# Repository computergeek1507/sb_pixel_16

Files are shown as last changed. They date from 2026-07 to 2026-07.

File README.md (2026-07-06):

# SBPixel16




A 16-port WS2812 pixel controller built on the **ESP32-P4**. It drives all 16 LED
strips simultaneously using the ESP32-P4's PARLIO peripheral for glitch-free parallel
DMA output. Pixel data comes from Ethernet (E1.31/sACN or DDP) or from **FSEQ
sequences played off a microSD card** in a standalone loop.

> **⚠️ WIP — Do not use.** Both the hardware and firmware are under active
> development and have not been fully validated.

This repository contains both the open-source **hardware** (KiCad 10) and the
**firmware** (Arduino / ESP-IDF).

---

## Features

- **16 parallel pixel outputs** — all strips clocked out together via PARLIO DMA,
  no RMT channel juggling.
- **Network input** — E1.31 (sACN, UDP 5568) or DDP (UDP 4048), selectable at runtime.
- **Standalone FSEQ playback** — plays uncompressed FSEQ v2 sequences (full or sparse)
  from a microSD card, looping the whole `/sequences` folder forever. No network needed.
- **Single-universe DMX512 output** — optional, generated on UART1 (250 kbaud, 8N2).
- **Web UI + REST API** — configure network, protocol, and per-port settings from a
  browser; config persists in LittleFS as `/config.json`.
- **On-OLED network setup** — set DHCP / static IP / gateway from the front-panel
  buttons, no computer required.
- **Over-the-air updates** — firmware and filesystem images can be flashed from the web UI.
- **Per-port configuration** — pixel count, start channel, color order, brightness,
  null/sacrificial pixels, and pixel grouping.
- **On-board 128×64 SSD1306 OLED** — shows IP, protocol, FPS, packet count, input
  voltages, SD status, and the currently playing sequence.
- **Two input-voltage monitors** — oversampled ADC readings (V1/V2) shown on the OLED.
- **Built-in test patterns** — cycle red / green / blue / rainbow with the on-board
  buttons; power-up RGB self-test on every boot.

---

## Repository layout

```
.
├── firmware/SBPixel16/     Arduino sketch (ESP32-P4)
│   ├── SBPixel16.ino        main app: setup/loop, config, Ethernet, parsers
│   ├── SBPixel16.h          board pin map & config structs
│   ├── parlio_ws2812.h      PARLIO parallel WS2812 DMA driver
│   ├── dmx_output.h         single-universe DMX512 output
│   ├── fseq_player.h        microSD FSEQ v2 player (uncompressed/sparse)
│   ├── net_menu.h           two-button OLED network editor
│   ├── data/                web UI source (packed into the LittleFS image)
│   └── page_*.h             web UI pages + REST API handlers
├── hardware/                KiCad 10 project (schematics, PCB, libraries)
│   └── ESP32-P4_16.*        board design files
└── LICENSE                  CC BY-NC 4.0 (firmware)
```

---

## Firmware

### Target

- **Board:** ESP32-P4 (Arduino-ESP32 3.x), e.g. Waveshare ESP32-P4-ETH
- **Ethernet PHY:** IP101GRI (RMII)
- **microSD:** the module's SDIO slot (4-bit) — used for FSEQ playback
- **Partition:** Default 4MB with SPIFFS (1.2 MB app / 1.5 MB filesystem)

### Required libraries

Install via the Arduino Library Manager:

| Library | Source |
| --- | --- |
| ESPAsyncWebServer | github.com/ESP32Async/ESPAsyncWebServer |
| AsyncTCP | github.com/ESP32Async/AsyncTCP |
| ArduinoJson | arduinojson.org |
| Adafruit GFX + Adafruit SSD1306 | Adafruit (OLED display) |

### Build & flash

1. Install the ESP32 board package (Arduino-ESP32 **3.x**) and select an **ESP32-P4** board.
2. **Enable PSRAM** (Tools → PSRAM → *Enabled* = `-DBOARD_HAS_PSRAM`). The module has
   PSRAM but the board default is *Disabled*, which leaves it uninitialized.
3. Set the partition scheme to **Default 4MB with SPIFFS**.
4. Open `firmware/SBPixel16/SBPixel16.ino`, compile, and upload.
5. Upload the web UI: flash the LittleFS filesystem image — a prebuilt
   `SBPixel16.littlefs.bin` is provided, or re-flash it over the air from the web UI.

On first boot with no `/config.json`, the firmware writes sensible defaults
(DHCP on, E1.31, 100 pixels/port, RGB order, 30% brightness).

**Board revisions:** the default build targets **HW1** (original pin map). Build for
the revised **HW2** board (pixel ports 12–16 rerouted off the USB pins onto
GPIO32/33/46/47/48) with `-DHW_VERSION=2`.

**Prebuilt binaries:** every push builds HW1 + HW2 firmware and the KiCad fabrication
outputs in CI — download them from the repo's **Actions** tab. When flashing over
serial after an OTA, use the `.merged.bin` (or first `esptool erase-region 0xe000
0x2000`), otherwise the bootloader keeps booting the previous OTA partition.

### REST API

| Method | Endpoint | Purpose |
| --- | --- | --- |
| GET | `/api/status` | Runtime stats (FPS, packet counts, voltages, SD/FSEQ status) |
| GET | `/api/config` | Current configuration as JSON |
| POST | `/api/config` | Update configuration |
| POST | `/api/reboot` | Reboot the controller |
| POST | `/api/ota/firmware` | Upload a firmware image |
| POST | `/api/ota/filesystem` | Upload a filesystem (web UI) image |

### Key defaults

- Refresh rate: ~40 fps (25 ms frame interval)
- Max pixels per port: 340 (configurable in `SBPixel16.h`)
- Input protocols: `0` = E1.31, `1` = DDP, `2` = FSEQ (SD card)
- Data timeout: outputs blank after 1 s with no packets
- E1.31 UDP port 5568 · DDP UDP port 4048 · HTTP port 80

### Front-panel controls (two buttons)

| Button | Action |
| --- | --- |
| **BTN1** tap | Cycle test pattern: Off → Red → Green → Blue → Rainbow → Off |
| **BTN2** tap | Stop the test pattern |
| **BTN2** hold (~1.5 s) | Open the `NETWORK SETUP` menu on the OLED |

**In the network menu:** **BTN1** changes the value under the cursor (hold to
auto-repeat), **BTN2** advances to the next field. Order: DHCP on/off → IP →
gateway → *Save & reboot*. Saving writes the config and reboots; 30 s of inactivity
cancels. Lets you set a static IP without a computer.

### FSEQ playback (microSD)

The microSD card is mounted at boot in every mode — its status shows on the OLED
(a card icon in the header) and the web dashboard. Set the input protocol to **FSEQ**
(Network page, or `protocol: 2`) to play from it: the controller scans **`/sequences`**
for `*.fseq` files, plays them alphabetically, and loops the whole folder forever — no
network connection required.

- **Format:** FSEQ v2, **uncompressed only** (full or sparse frames). Export from
  xLights / FPP with *No Compression*. Compressed files are skipped.
- **Channel mapping:** frame channels map to ports by each port's **Start Ch.**, exactly
  like E1.31/DDP — so brightness, color order, and grouping all still apply.
- The OLED and the web dashboard show the mounted card and the sequence now playing.

---

## Hardware

The board is a KiCad 10 open-hardware design (`hardware/ESP32-P4_16.*`) with 16 buffered
pixel outputs, dual power inputs with voltage monitoring, an SSD1306 OLED, two buttons,
and RMII Ethernet.

Design files, interactive BOM, and part list are published on the upstream project:

- **Interactive BOM:** https://computergeek1507.github.io/PB_16/ESP32-P4_16/bom/ibom
- **Part BOM (.ods):** https://github.com/computergeek1507/PB_16/raw/master/ESP32-P4_16/ESP32-P4_16_BOM.ods

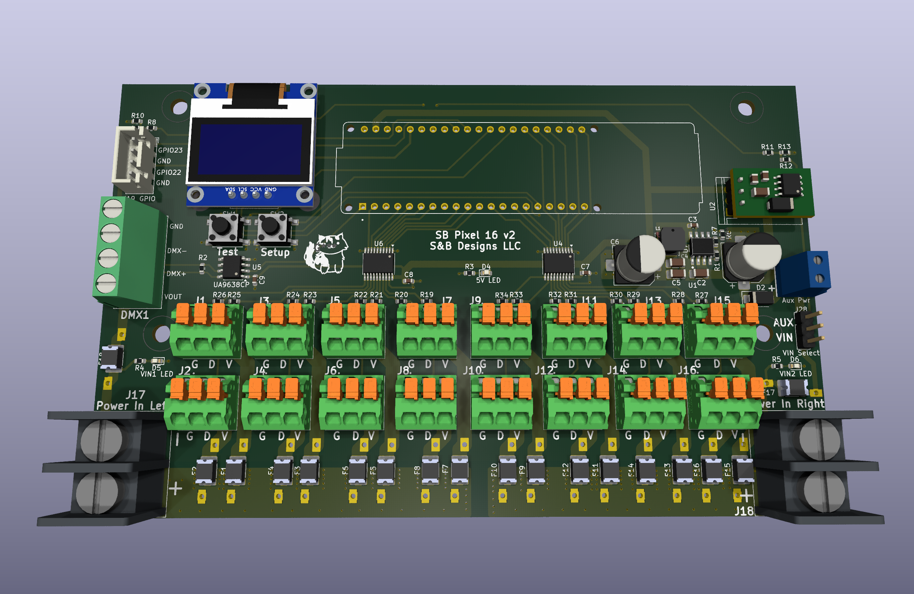
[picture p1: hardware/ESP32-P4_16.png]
ESP32-P4 16 board


---

## Licensing

Both the **firmware** and the **hardware** are licensed under **CC BY-NC 4.0**
(see [LICENSE](LICENSE)) — free to share and adapt for non-commercial use with
attribution.

Copyright © 2025 Scott Hanson.

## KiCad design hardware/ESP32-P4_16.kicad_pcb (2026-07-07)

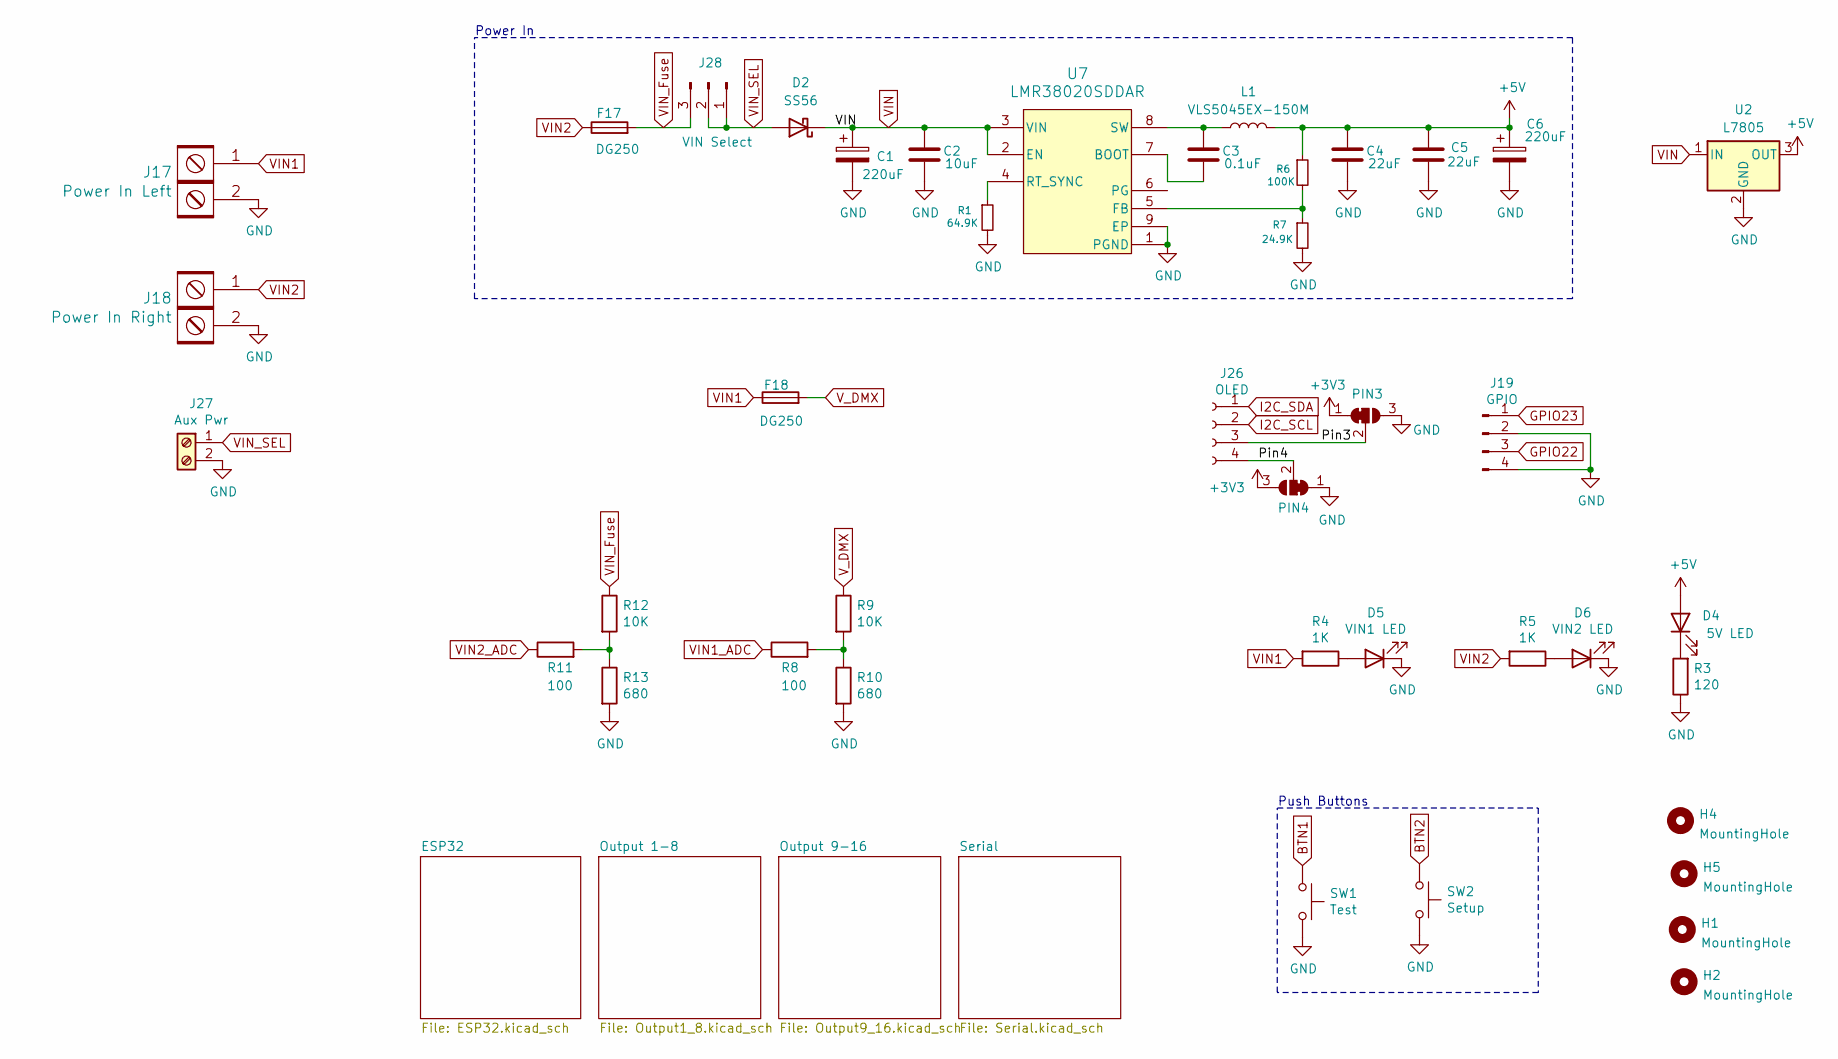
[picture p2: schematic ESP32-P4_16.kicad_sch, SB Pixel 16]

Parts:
C1, C6: 220uF; CP_Elec_8x10.5; LCSC C3340
C2: 10uF; C_1206_3216Metric; LCSC_PN C13585
C3: 0.1uF; C_0603_1608Metric; MPN CC0603KRX7R9BB104; LCSC C14663
C4, C5: 22uF; C_1206_3216Metric; LCSC_PN C1859
D2: SS56; D_SMA; LCSC C65009
D4: 5V LED; LED_0603_1608Metric; MPN LTST-C190KRKT; Digi-Key_PN 160-1436-2-ND
D5: VIN1 LED; LED_0603_1608Metric; MPN LTST-C190KRKT; Digi-Key_PN 160-1436-2-ND
D6: VIN2 LED; LED_0603_1608Metric; MPN LTST-C190KRKT; Digi-Key_PN 160-1436-2-ND
F17: DG250; Fuse_1812_4532Metric; MPN 3544-2
F18: DG250; Fuse_1812_4532Metric
H1, H2, H4, H5: MountingHole; MountingHole_3.7mm
J17: Power In Left; BARRIER_BLOCK_1ROW_2POS_P9.5MM; MPN OSTYK51102030; Digi-Key_PN ED2953-ND
J18: Power In Right; BARRIER_BLOCK_1ROW_2POS_P9.5MM; MPN OSTYK51102030; Digi-Key_PN ED2953-ND
J19: GPIO; JST_XH_B4B-XH-A_1x04_P2.50mm_Vertical; MPN B4B-XH-A(LF)(SN); Digi-Key_PN 455-2249-ND
J26: OLED; OLED-SSD1306-128X64-I2C-THT_2HOLE; MPN PPTC041LFBN-RC; Digi-Key_PN S7002-ND
J27: Aux Pwr; PHOENIX_MKDS1_2-3.81; MPN 1727010; Digi-Key_PN 277-1947-ND
J28: VIN Select; PinHeader_1x03_P2.54mm_Vertical; MPN 61300311121; Digi-Key_PN 732-5316-ND
L1: VLS5045EX-150M; IND_VLS5045EX-150M; MPN VLS5045EX-150M; Digi-Key_PN 445-174845-1-ND
PIN3: Jumper; SolderJumper-3_P1.3mm_Bridged12_Pad1.0x1.5mm
PIN4: JUMPER; SolderJumper-3_P1.3mm_Bridged12_Pad1.0x1.5mm
R1: 64.9K; R_0603_1608Metric; LCSC C14891
R3: 120; R_0603_1608Metric; MPN CRGCQ0603F120R; Digi-Key_PN A129677CT-ND
R4, R5: 1K; R_0603_1608Metric; MPN RC0603FR-071KL; Digi-Key_PN 311-1.00KHRTR-ND
R6: 100K; R_0603_1608Metric; LCSC C25803
R7: 24.9K; R_0603_1608Metric; LCSC C25962
R8, R11: 100; R_0603_1608Metric; MPN RMCF0603FT100R; Digi-Key_PN RMCF0603FT100RCT-ND
R9, R12: 10K; R_0603_1608Metric; MPN RC0603FR-0710KL; Digi-Key_PN 311-10.0KHRCT-ND
R10, R13: 680; R_0603_1608Metric; MPN RC0603FR-07680RL; Digi-Key_PN 311-680HRCT-ND
SW1: Test; SW_Push_1P1T_NO_6x6mm_H9.5mm; MPN PTS645SL50SMTR92 LFS; Digi-Key_PN CKN9088CT-ND
SW2: Setup; SW_Push_1P1T_NO_6x6mm_H9.5mm; MPN PTS645SL50SMTR92 LFS; Digi-Key_PN CKN9088CT-ND
U2: L7805; OKI-78SR_Horz
U7: LMR38020SDDAR; DDA0008E-IPC_A; MPN LMR38020SDDAR; Digi-Key_PN 296-LMR38020SDDARCT-ND

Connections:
+3V3: PIN3.1 (A), PIN4.3 (B); also elsewhere on the board
+5V: C4.1, C5.1, C6.1, D4.2 (A), L1.2, R6.1, U2.3 (OUT); also elsewhere on the board
/Pin3: J26.3, PIN3.2 (C)
/Pin4: J26.4, PIN4.2 (C)
BTN1: SW1.1; also elsewhere on the board
BTN2: SW2.1; also elsewhere on the board
GND: C1.2, C2.2, C4.2, C5.2, C6.2, D5.1 (K), D6.1 (K), J17.2, J18.2, J19.2, J19.4, J27.2, PIN3.3 (B), PIN4.1 (A), R1.2, R3.1, R7.2, R10.2, R13.2, SW1.2, SW2.2, U2.2 (GND), U7.1 (PGND), U7.9 (EP); also elsewhere on the board
GPIO22: J19.3; also elsewhere on the board
GPIO23: J19.1; also elsewhere on the board
I2C_SCL: J26.2; also elsewhere on the board
I2C_SDA: J26.1; also elsewhere on the board
unnamed: D4.1 (K), R3.2
unnamed: D5.2 (A), R4.1
unnamed: D6.2 (A), R5.1
unnamed: R8.2, R9.2, R10.1
unnamed: R11.2, R12.2, R13.1
unnamed: C3.2, U7.7 (BOOT)
unnamed: R6.2, R7.1, U7.5 (FB)
unnamed: R1.1, U7.4 (RT_SYNC)
unnamed: C3.1, L1.1, U7.8 (SW)
VIN: C1.1, C2.1, D2.1 (K), U2.1 (IN), U7.2 (EN), U7.3 (VIN)
VIN1: F18.1, J17.1, R4.2; also elsewhere on the board
VIN1_ADC: R8.1; also elsewhere on the board
VIN2: F17.1, J18.1, R5.2; also elsewhere on the board
VIN2_ADC: R11.1; also elsewhere on the board
VIN_Fuse: F17.2, J28.3, R12.1
VIN_SEL: D2.2 (A), J27.1, J28.1, J28.2
V_DMX: F18.2, R9.1; also elsewhere on the board

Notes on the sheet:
Push Buttons
Power In

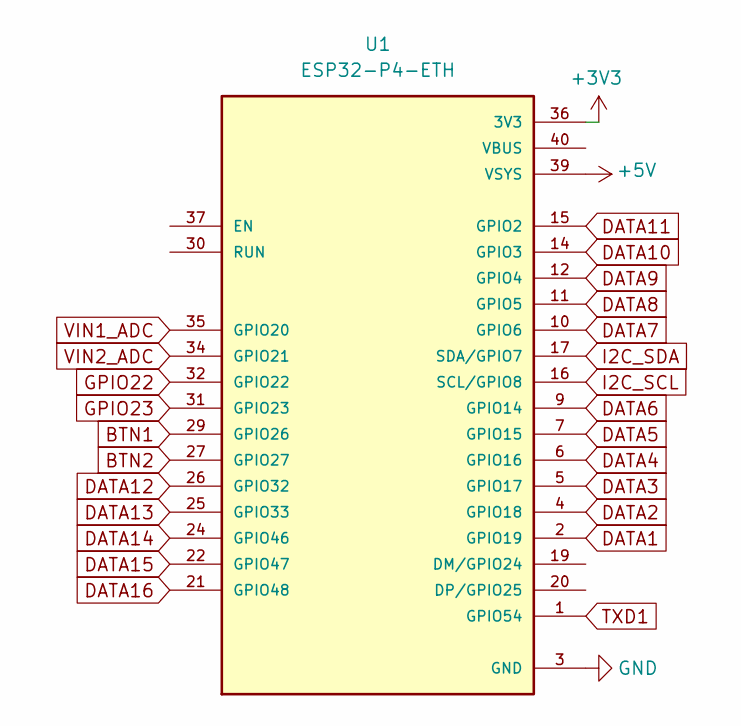
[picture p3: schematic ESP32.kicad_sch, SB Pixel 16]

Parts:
U1: ESP32-P4-ETH; MODULE_ESP32-P4-ETH

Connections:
+3V3: U1.36 (3V3); also elsewhere on the board
+5V: U1.39 (VSYS); also elsewhere on the board
BTN1: U1.29 (GPIO26); also elsewhere on the board
BTN2: U1.27 (GPIO27); also elsewhere on the board
DATA1: U1.2 (GPIO19); also elsewhere on the board
DATA2: U1.4 (GPIO18); also elsewhere on the board
DATA3: U1.5 (GPIO17); also elsewhere on the board
DATA4: U1.6 (GPIO16); also elsewhere on the board
DATA5: U1.7 (GPIO15); also elsewhere on the board
DATA6: U1.9 (GPIO14); also elsewhere on the board
DATA7: U1.10 (GPIO6); also elsewhere on the board
DATA8: U1.11 (GPIO5); also elsewhere on the board
DATA9: U1.12 (GPIO4); also elsewhere on the board
DATA10: U1.14 (GPIO3); also elsewhere on the board
DATA11: U1.15 (GPIO2); also elsewhere on the board
DATA12: U1.26 (GPIO32); also elsewhere on the board
DATA13: U1.25 (GPIO33); also elsewhere on the board
DATA14: U1.24 (GPIO46); also elsewhere on the board
DATA15: U1.22 (GPIO47); also elsewhere on the board
DATA16: U1.21 (GPIO48); also elsewhere on the board
GND: U1.3 (GND), U1.8 (GND), U1.13 (GND), U1.18 (GND), U1.23 (GND), U1.28 (GND), U1.33 (GND), U1.38 (GND); also elsewhere on the board
GPIO22: U1.32 (GPIO22); also elsewhere on the board
GPIO23: U1.31 (GPIO23); also elsewhere on the board
I2C_SCL: U1.16 (SCL/GPIO8); also elsewhere on the board
I2C_SDA: U1.17 (SDA/GPIO7); also elsewhere on the board
TXD1: U1.1 (GPIO54); also elsewhere on the board
VIN1_ADC: U1.35 (GPIO20); also elsewhere on the board
VIN2_ADC: U1.34 (GPIO21); also elsewhere on the board

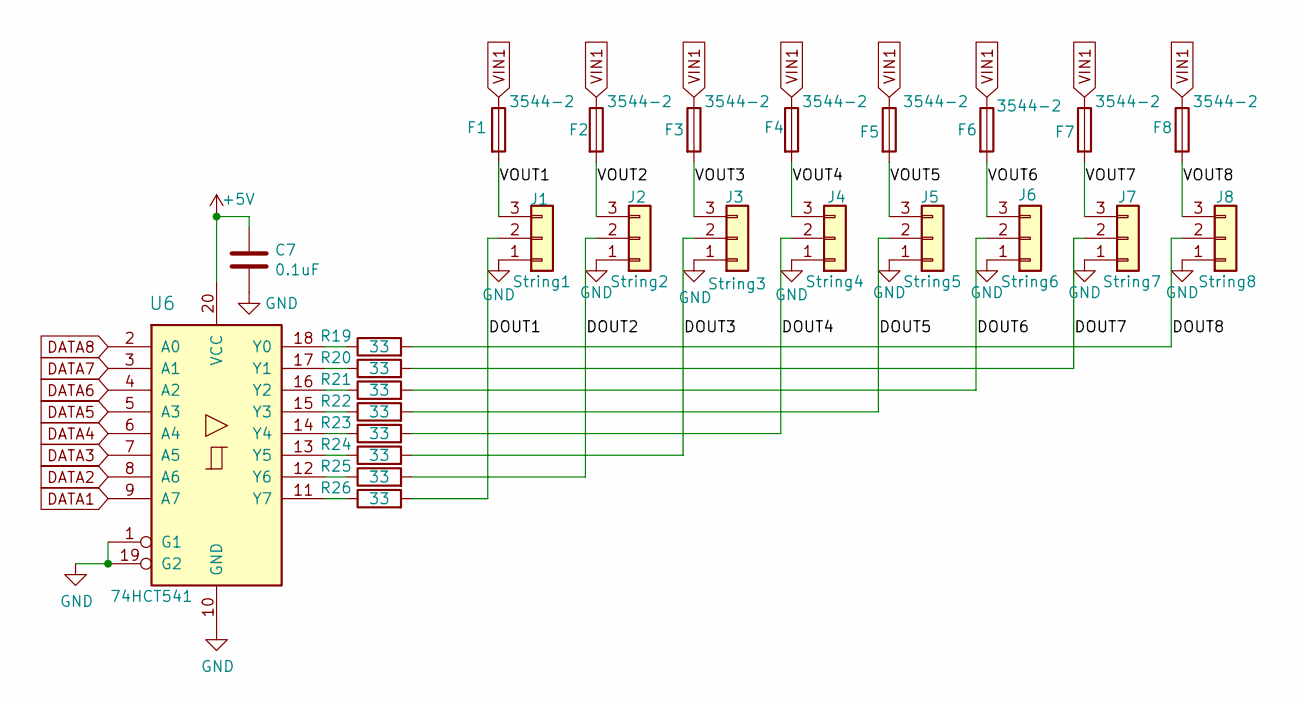
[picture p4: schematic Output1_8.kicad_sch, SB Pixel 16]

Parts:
C7: 0.1uF; C_0603_1608Metric; MPN CL10B104KB8NNWC; Digi-Key_PN 1276-1935-2-ND
F1, F2, F3, F4, F5, F6, F7, F8: 3544-2; Fuse_1812_4532Metric; MPN 3544-2
J1: String1; PHOENIX_1864299_1; MPN 1843619/OSTTJ0311530
J2: String2; PHOENIX_1864299_1; MPN 1843619/OSTTJ0311530
J3: String3; PHOENIX_1864299_1; MPN 1843619/OSTTJ0311530
J4: String4; PHOENIX_1864299_1; MPN 1843619/OSTTJ0311530
J5: String5; PHOENIX_1864299_1; MPN 1843619/OSTTJ0311530
J6: String6; PHOENIX_1864299_1; MPN 1843619/OSTTJ0311530
J7: String7; PHOENIX_1864299_1; MPN 1843619/OSTTJ0311530
J8: String8; PHOENIX_1864299_1; MPN 1843619/OSTTJ0311530
R19, R20, R21, R22, R23, R24, R25, R26: 33; R_0603_1608Metric; MPN CN34J330CT; LCSC C23140
U6: 74HCT541; TSSOP-20_4.4x6.5mm_P0.65mm; MPN SN74HCT541PWR; Digi-Key_PN MC74HCT541ADTR2GOSTR-ND

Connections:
+5V: C7.1, U6.20 (VCC); also elsewhere on the board
/Output 1-8/DOUT1: J1.2, R26.2
/Output 1-8/DOUT2: J2.2, R25.2
/Output 1-8/DOUT3: J3.2, R24.2
/Output 1-8/DOUT4: J4.2, R23.2
/Output 1-8/DOUT5: J5.2, R22.2
/Output 1-8/DOUT6: J6.2, R21.2
/Output 1-8/DOUT7: J7.2, R20.2
/Output 1-8/DOUT8: J8.2, R19.2
/Output 1-8/VOUT1: F1.2, J1.3
/Output 1-8/VOUT2: F2.2, J2.3
/Output 1-8/VOUT3: F3.2, J3.3
/Output 1-8/VOUT4: F4.2, J4.3
/Output 1-8/VOUT5: F5.2, J5.3
/Output 1-8/VOUT6: F6.2, J6.3
/Output 1-8/VOUT7: F7.2, J7.3
/Output 1-8/VOUT8: F8.2, J8.3
DATA1: U6.9 (A7); also elsewhere on the board
DATA2: U6.8 (A6); also elsewhere on the board
DATA3: U6.7 (A5); also elsewhere on the board
DATA4: U6.6 (A4); also elsewhere on the board
DATA5: U6.5 (A3); also elsewhere on the board
DATA6: U6.4 (A2); also elsewhere on the board
DATA7: U6.3 (A1); also elsewhere on the board
DATA8: U6.2 (A0); also elsewhere on the board
GND: C7.2, J1.1, J2.1, J3.1, J4.1, J5.1, J6.1, J7.1, J8.1, U6.1 (G1), U6.10 (GND), U6.19 (G2); also elsewhere on the board
unnamed: R19.1, U6.18 (Y0)
unnamed: R20.1, U6.17 (Y1)
unnamed: R21.1, U6.16 (Y2)
unnamed: R22.1, U6.15 (Y3)
unnamed: R23.1, U6.14 (Y4)
unnamed: R24.1, U6.13 (Y5)
unnamed: R25.1, U6.12 (Y6)
unnamed: R26.1, U6.11 (Y7)
VIN1: F1.1, F2.1, F3.1, F4.1, F5.1, F6.1, F7.1, F8.1; also elsewhere on the board

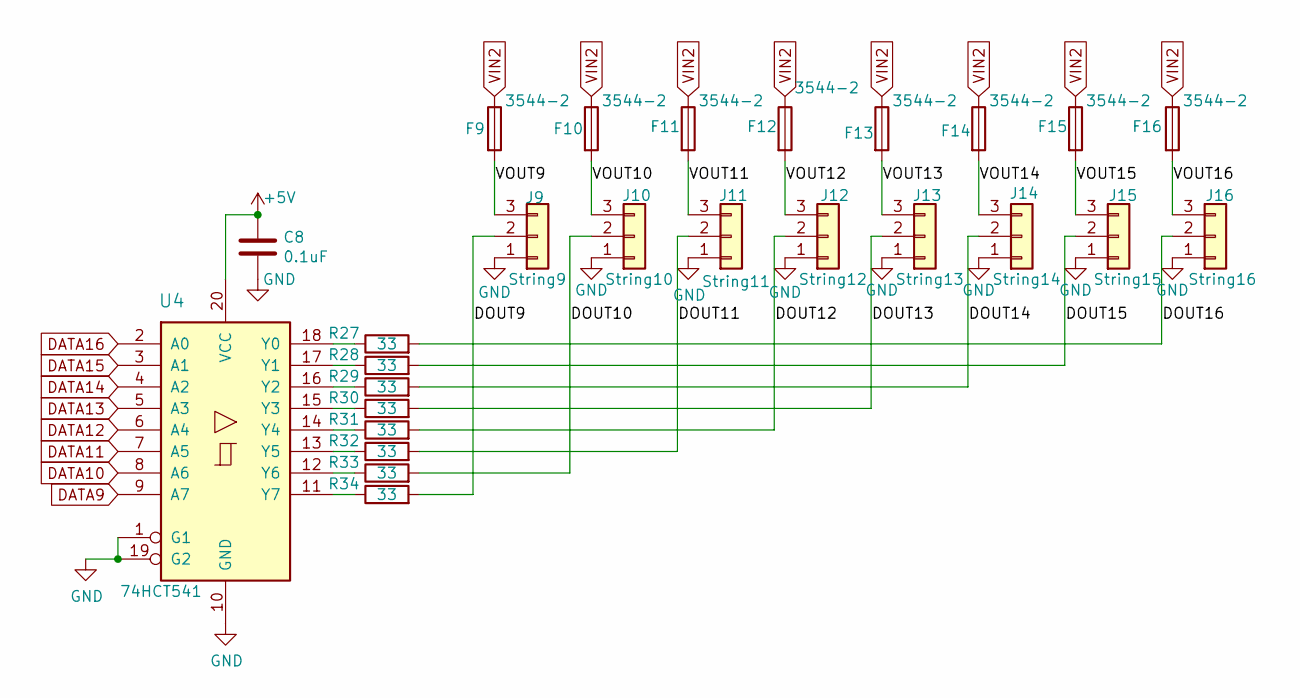
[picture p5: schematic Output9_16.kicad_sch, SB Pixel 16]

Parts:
C8: 0.1uF; C_0603_1608Metric; MPN CL10B104KB8NNWC; Digi-Key_PN 1276-1935-2-ND
F9, F10, F11, F12, F13, F14, F15, F16: 3544-2; Fuse_1812_4532Metric; MPN 3544-2
J9: String9; PHOENIX_1864299_1; MPN 1843619/OSTTJ0311530
J10: String10; PHOENIX_1864299_1; MPN 1843619/OSTTJ0311530
J11: String11; PHOENIX_1864299_1; MPN 1843619/OSTTJ0311530
J12: String12; PHOENIX_1864299_1; MPN 1843619/OSTTJ0311530
J13: String13; PHOENIX_1864299_1; MPN 1843619/OSTTJ0311530
J14: String14; PHOENIX_1864299_1; MPN 1843619/OSTTJ0311530
J15: String15; PHOENIX_1864299_1; MPN 1843619/OSTTJ0311530
J16: String16; PHOENIX_1864299_1; MPN 1843619/OSTTJ0311530
R27, R28, R29, R30, R31, R32, R33, R34: 33; R_0603_1608Metric; MPN CN34J330CT; LCSC C23140
U4: 74HCT541; TSSOP-20_4.4x6.5mm_P0.65mm; MPN SN74HCT541PWR; Digi-Key_PN MC74HCT541ADTR2GOSTR-ND

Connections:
+5V: C8.1, U4.20 (VCC); also elsewhere on the board
/Output 9-16/DOUT9: J9.2, R34.2
/Output 9-16/DOUT10: J10.2, R33.2
/Output 9-16/DOUT11: J11.2, R32.2
/Output 9-16/DOUT12: J12.2, R31.2
/Output 9-16/DOUT13: J13.2, R30.2
/Output 9-16/DOUT14: J14.2, R29.2
/Output 9-16/DOUT15: J15.2, R28.2
/Output 9-16/DOUT16: J16.2, R27.2
/Output 9-16/VOUT9: F9.2, J9.3
/Output 9-16/VOUT10: F10.2, J10.3
/Output 9-16/VOUT11: F11.2, J11.3
/Output 9-16/VOUT12: F12.2, J12.3
/Output 9-16/VOUT13: F13.2, J13.3
/Output 9-16/VOUT14: F14.2, J14.3
/Output 9-16/VOUT15: F15.2, J15.3
/Output 9-16/VOUT16: F16.2, J16.3
DATA9: U4.9 (A7); also elsewhere on the board
DATA10: U4.8 (A6); also elsewhere on the board
DATA11: U4.7 (A5); also elsewhere on the board
DATA12: U4.6 (A4); also elsewhere on the board
DATA13: U4.5 (A3); also elsewhere on the board
DATA14: U4.4 (A2); also elsewhere on the board
DATA15: U4.3 (A1); also elsewhere on the board
DATA16: U4.2 (A0); also elsewhere on the board
GND: C8.2, J9.1, J10.1, J11.1, J12.1, J13.1, J14.1, J15.1, J16.1, U4.1 (G1), U4.10 (GND), U4.19 (G2); also elsewhere on the board
unnamed: R27.1, U4.18 (Y0)
unnamed: R28.1, U4.17 (Y1)
unnamed: R29.1, U4.16 (Y2)
unnamed: R30.1, U4.15 (Y3)
unnamed: R31.1, U4.14 (Y4)
unnamed: R32.1, U4.13 (Y5)
unnamed: R33.1, U4.12 (Y6)
unnamed: R34.1, U4.11 (Y7)
VIN2: F9.1, F10.1, F11.1, F12.1, F13.1, F14.1, F15.1, F16.1; also elsewhere on the board

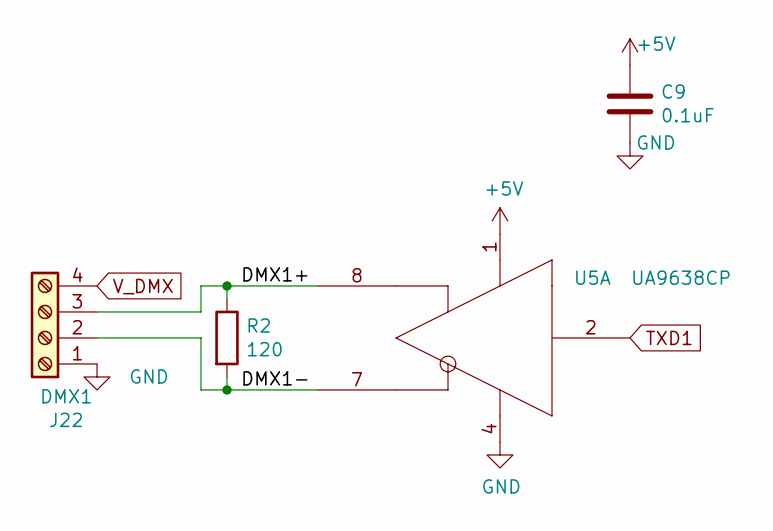
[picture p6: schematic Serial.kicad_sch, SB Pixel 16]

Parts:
C9: 0.1uF; C_0603_1608Metric; MPN CL10B104KB8NNWC; Digi-Key_PN 1276-1935-2-ND
J22: DMX1; TerminalBlock_Phoenix_MKDS-1,5-4_1x04_P5.00mm_Horizontal; MPN 1729034; Digi-Key_PN 277-1238-ND
R2: 120; R_0603_1608Metric; MPN CRGCQ0603F120R; Digi-Key_PN A129677CT-ND
U5: UA9638CP; SOIC-8_3.9x4.9mm_P1.27mm; MPN UA9638CDR; Digi-Key_PN UA9638CP

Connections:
+5V: C9.1, U5.1 (VCC); also elsewhere on the board
/Serial/DMX1+: J22.3, R2.1, U5.8 (OUTB)
/Serial/DMX1-: J22.2, R2.2, U5.7 (OUTA)
GND: C9.2, J22.1, U5.4 (GND); also elsewhere on the board
TXD1: U5.2 (IN); also elsewhere on the board
V_DMX: J22.4; also elsewhere on the board

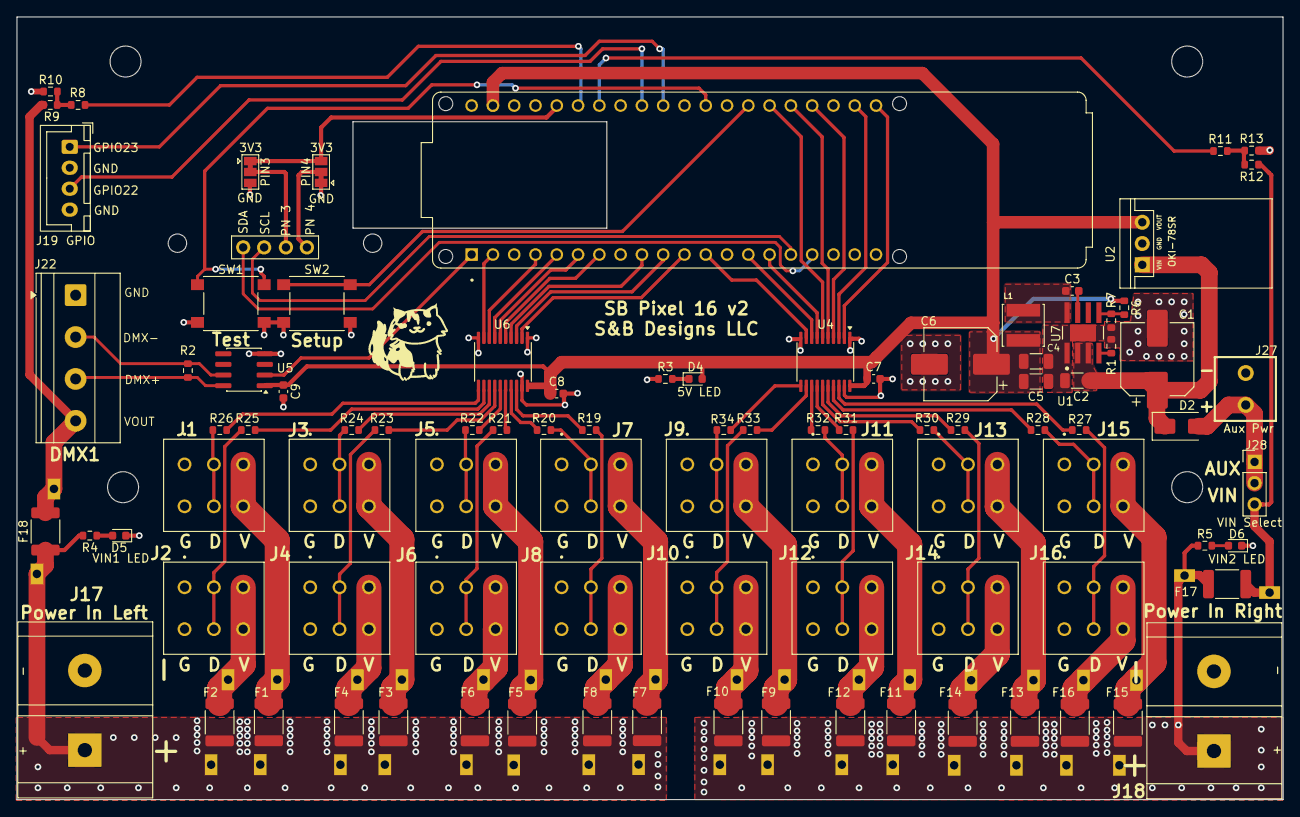
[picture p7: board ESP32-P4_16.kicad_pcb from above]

Board: 2 copper layers, 151.1 x 93.4 mm, 98 parts (0 on the bottom side), 95 nets.

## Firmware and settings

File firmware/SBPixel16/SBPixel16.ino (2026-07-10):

/*
 * SBPixel16.ino
 *
 * 16-port WS2812 pixel controller for ESP32-P4-EV
 * Input: E1.31 (sACN) or DDP over Ethernet
 * Config: web UI + REST API, stored in LittleFS as /config.json
 * Output: PARLIO parallel DMA — all 16 strips driven simultaneously
 *
 * Libraries required (install via Arduino Library Manager):
 *   ESPAsyncWebServer  github.com/me-no-dev/ESPAsyncWebServer
 *   AsyncTCP           github.com/me-no-dev/AsyncTCP
 *   ArduinoJson        arduinojson.org
 *
 * Board: ESP32-P4 (Arduino-ESP32 3.x)
 * Partition: Default 4MB with SPIFFS (1.2MB APP / 1.5MB FS)
 */

#include <ETH.h>
#include <NetworkUdp.h>
#include <AsyncTCP.h>
#include <ESPAsyncWebServer.h>
#include <LittleFS.h>
#include <ArduinoJson.h>
#include <Wire.h>
#include <Adafruit_GFX.h>
#include <Adafruit_SSD1306.h>

#include "SBPixel16.h"
#include "parlio_ws2812.h"
#include "dmx_output.h"
#include "fseq_player.h"
#include "net_menu.h"
#include "page_index.h"
#include "page_config.h"
#include "page_ota.h"

// ── Globals ───────────────────────────────────────────────────────────────────

AppConfig cfg;

// Raw channel data received from E1.31 / DDP (RGB, per logical pixel)
static uint8_t rawBuf[NUM_PORTS][MAX_PIXELS * 3];

uint32_t g_e131Packets = 0;
uint32_t g_ddpPackets  = 0;
uint32_t g_fps         = 0;
uint32_t g_lastPacket  = 0;
uint32_t g_vin1_mv     = 0;
uint32_t g_vin2_mv     = 0;
uint8_t  g_testMode    = 0;
uint8_t  g_testPort    = 0;

bool              g_parlioOk  = false;
volatile bool     g_menuActive = false;
volatile uint32_t g_b1HeldMs  = 0;
volatile bool     g_otaActive = false;
volatile uint32_t g_otaLastMs = 0;
volatile uint32_t g_otaFlashMs = 0;
volatile uint8_t  g_otaMode    = 0;

bool     g_sdMounted   = false;
uint32_t g_sdSizeMB    = 0;
uint16_t g_fseqCount   = 0;
uint32_t g_fseqFrame   = 0;
uint32_t g_fseqFrames  = 0;
char     g_fseqName[32] = {0};
char     g_sdError[24]  = {0};

static bool          s_ethConnected = false;
static AsyncWebServer web(HTTP_PORT);
static NetworkUDP    e131Udp;
static NetworkUDP    ddpUdp;
static ParlioWs2812  parlio;
static DmxOutput     dmx;
static FseqPlayer    fseq;
static NetMenu       netMenu;

static uint8_t dmxBuf[512];

static Adafruit_SSD1306 oled(OLED_W, OLED_H, &Wire, -1);
static bool             s_oledFound = false;

// ── E1.31 packet buffer (638 bytes) ──────────────────────────────────────────
static uint8_t e131Buf[638];

static const uint8_t ACN_ID[12] = {
    0x41,0x53,0x43,0x2d,0x45,0x31,0x2e,0x31,0x37,0x00,0x00,0x00
};

// ── DDP packet buffer ─────────────────────────────────────────────────────────
static uint8_t ddpBuf[1450];

// ── Config load / save ────────────────────────────────────────────────────────

void configToJSON(String &out) {
    JsonDocument doc;

    JsonObject net   = doc["network"].to<JsonObject>();
    net["dhcp"]      = cfg.dhcp;
    net["ip"]        = cfg.ip;
    net["subnet"]    = cfg.subnet;
    net["gateway"]   = cfg.gateway;

    doc["protocol"]      = cfg.protocol;
    doc["universeStart"] = cfg.uniStart;
    doc["universeSize"]  = cfg.uniSize;

    JsonArray ports = doc["ports"].to<JsonArray>();
    for (int i = 0; i < NUM_PORTS; i++) {
        JsonObject p      = ports.add<JsonObject>();
        p["pixelCount"]   = cfg.ports[i].pixelCount;
        p["startChannel"] = cfg.ports[i].startChannel;
        p["colorOrder"]   = cfg.ports[i].colorOrder;
        p["nullPixels"]   = cfg.ports[i].nullPixels;
        p["grouping"]     = cfg.ports[i].grouping;
        p["brightness"]   = cfg.ports[i].brightness;
    }

    doc["dmxEnabled"]  = cfg.dmxEnabled;
    doc["dmxStartCh"]  = cfg.dmxStartCh;
    doc["dmxChannels"] = cfg.dmxChannels;

    serializeJson(doc, out);
}

bool jsonToConfig(const String &json) {
    JsonDocument doc;
    if (deserializeJson(doc, json) != DeserializationError::Ok) return false;

    JsonObject net = doc["network"];
    if (!net.isNull()) {
        if (net["dhcp"].is<bool>())           cfg.dhcp    = net["dhcp"].as<bool>();
        if (net["ip"].is<const char*>())      cfg.ip      = net["ip"].as<String>();
        if (net["subnet"].is<const char*>())  cfg.subnet  = net["subnet"].as<String>();
        if (net["gateway"].is<const char*>()) cfg.gateway = net["gateway"].as<String>();
    }

    if (doc["protocol"].is<int>())      cfg.protocol = doc["protocol"].as<uint8_t>();
    if (doc["universeStart"].is<int>()) cfg.uniStart = doc["universeStart"].as<uint16_t>();
    if (doc["universeSize"].is<int>())  cfg.uniSize  = doc["universeSize"].as<uint16_t>();

    JsonArray ports = doc["ports"].as<JsonArray>();
    int i = 0;
    for (JsonObject p : ports) {
        if (i >= NUM_PORTS) break;
        if (p["pixelCount"].is<int>())   cfg.ports[i].pixelCount   = p["pixelCount"].as<uint16_t>();
        if (p["startChannel"].is<int>()) cfg.ports[i].startChannel = p["startChannel"].as<uint32_t>();
        if (p["colorOrder"].is<int>())   cfg.ports[i].colorOrder   = p["colorOrder"].as<uint8_t>();
        if (p["nullPixels"].is<int>())   cfg.ports[i].nullPixels   = p["nullPixels"].as<uint8_t>();
        if (p["grouping"].is<int>())     cfg.ports[i].grouping     = p["grouping"].as<uint8_t>();
        if (p["brightness"].is<int>())   cfg.ports[i].brightness   = p["brightness"].as<uint8_t>();
        i++;
    }
    if (doc["dmxEnabled"].is<bool>())  cfg.dmxEnabled  = doc["dmxEnabled"].as<bool>();
    if (doc["dmxStartCh"].is<int>())   cfg.dmxStartCh  = doc["dmxStartCh"].as<uint32_t>();
    if (doc["dmxChannels"].is<int>())  cfg.dmxChannels = doc["dmxChannels"].as<uint16_t>();

    return true;
}

void defaultConfig() {
    cfg.dhcp     = true;
    cfg.ip       = "192.168.1.200";
    cfg.subnet   = "255.255.255.0";
    cfg.gateway  = "192.168.1.1";
    cfg.protocol   = PROTO_E131;
    cfg.uniStart   = 1;
    cfg.uniSize    = 510;
    for (int i = 0; i < NUM_PORTS; i++) {
        cfg.ports[i].pixelCount   = 100;
        cfg.ports[i].startChannel = (uint32_t)(i * 510) + 1;
        cfg.ports[i].colorOrder   = CO_RGB;
        cfg.ports[i].nullPixels   = 0;
        cfg.ports[i].grouping     = 1;
        cfg.ports[i].brightness   = 30;
    }
}

void saveConfig() {
    String json;
    configToJSON(json);
    File f = LittleFS.open(CONFIG_FILE, "w");
    if (f) { f.print(json); f.close(); }
    else    Serial.println("saveConfig: open failed");
}

void loadConfig() {
    defaultConfig();
    if (!LittleFS.exists(CONFIG_FILE)) {
        Serial.println("No config — writing defaults");
        saveConfig();
        return;
    }
    File f = LittleFS.open(CONFIG_FILE, "r");
    if (!f) return;
    String json = f.readString();
    f.close();
    if (!jsonToConfig(json))
        Serial.println("Config parse failed — using defaults");
}

// If the SD card has a /config.json, merge it over the current config (only
// fields present in the file are changed) and persist the result to LittleFS.
// Call after fseq.begin() — SD must already be mounted, and PARLIO must already
// be sized from the LittleFS config (setupParlio() runs before fseq.begin()).
// pixelCount/nullPixels/grouping determine PARLIO's DMA buffer size, which is
// fixed at parlio.begin() and can't be resized live — if the SD config changes
// any of those, reboot so the next boot sizes PARLIO correctly from the start.
void loadConfigFromSD() {
    if (!g_sdMounted) return;
    if (!SD_MMC.exists(SD_CONFIG_FILE)) {
        Serial.println("SD: no config.json found");
        return;
    }
    File f = SD_MMC.open(SD_CONFIG_FILE, FILE_READ);
    if (!f) { Serial.println("SD: config.json open failed"); return; }
    String json = f.readString();
    f.close();

    struct BufShape { uint16_t pixelCount; uint8_t nullPixels; uint8_t grouping; };
    BufShape before[NUM_PORTS];
    for (int i = 0; i < NUM_PORTS; i++)
        before[i] = { cfg.ports[i].pixelCount, cfg.ports[i].nullPixels, cfg.ports[i].grouping };

    if (!jsonToConfig(json)) {
        Serial.println("SD: config.json parse failed — ignoring");
        return;
    }

    bool resizesBuffer = false;
    for (int i = 0; i < NUM_PORTS; i++) {
        if (cfg.ports[i].pixelCount != before[i].pixelCount ||
            cfg.ports[i].nullPixels != before[i].nullPixels ||
            cfg.ports[i].grouping   != before[i].grouping) {
            resizesBuffer = true;
            break;
        }
    }

    saveConfig();   // mirror the merged config to LittleFS either way
    Serial.println("SD: config.json loaded");

    if (resizesBuffer) {
        Serial.println("SD: config changes pixel/null/grouping — rebooting to resize PARLIO");
        delay(200);
        ESP.restart();
    }
}

// ── Ethernet ──────────────────────────────────────────────────────────────────

void ethEvent(arduino_event_id_t event) {
    switch (event) {
    case ARDUINO_EVENT_ETH_START:
        Serial.println("ETH: started");
        ETH.setHostname("SBPixel16");
        break;
    case ARDUINO_EVENT_ETH_CONNECTED:
        Serial.println("ETH: link up");
        updateOLED();
        break;
    case ARDUINO_EVENT_ETH_GOT_IP:
        Serial.print("ETH: IP = "); Serial.println(ETH.localIP());
        s_ethConnected = true;
        e131Udp.begin(E131_UDP_PORT);
        ddpUdp.begin(DDP_UDP_PORT);
        Serial.println("UDP listeners started");
        updateOLED();
        break;
    case ARDUINO_EVENT_ETH_DISCONNECTED:
        Serial.println("ETH: link down");
        s_ethConnected = false;
        updateOLED();
        break;
    default: break;
    }
}

void setupEthernet() {
    Network.onEvent(ethEvent);

    if (!cfg.dhcp) {
        IPAddress ipAddr, ipSub, ipGw;
        if (!ipAddr.fromString(cfg.ip) || !ipSub.fromString(cfg.subnet) || !ipGw.fromString(cfg.gateway)) {
            Serial.println("Invalid IP in config — using defaults");
            ipAddr.fromString("192.168.1.200");
            ipSub.fromString("255.255.255.0");
            ipGw.fromString("192.168.1.1");
        }
        ETH.config(ipAddr, ipGw, ipSub);
        Serial.print("ETH: static IP = "); Serial.println(cfg.ip);
    } else {
        Serial.println("ETH: DHCP enabled");
    }

    ETH.begin(ETH_PHY_TYPE, ETH_PHY_ADDR, ETH_PHY_MDC, ETH_PHY_MDIO,
              ETH_PHY_POWER, ETH_CLK_MODE);
}

// ── OLED ──────────────────────────────────────────────────────────────────────

// 8x11 SD-card glyph (solid body with a notched top-right corner), shown in the
// top-right of the header while a card is mounted.
static const uint8_t SD_ICON[] = {
    0b11111000, 0b11111100, 0b11111110, 0b11111111, 0b11111111, 0b11100111,
    0b11111111, 0b11111111, 0b11111111, 0b11111111, 0b11111111,
};

void updateOLED() {
    if (!s_oledFound) return;
    if (netMenu.active()) { netMenu.render(oled); return; }
    oled.clearDisplay();
    oled.setTextSize(1);
    oled.setTextColor(SSD1306_WHITE);

    oled.setCursor(0, 0);
    oled.print("SBPixel16");
    if (g_testMode > 0) {
        oled.setCursor(58, 0);          // compact: "T:RAINBOW" fits before the SD icon
        oled.print("T:");
        oled.print(testModeName());
    }
    if (g_sdMounted)
        oled.drawBitmap(120, 0, SD_ICON, 8, 11, SSD1306_WHITE);

    oled.setCursor(0, 9);
    if (s_ethConnected) {
        oled.print(ETH.localIP().toString());
    } else {
        oled.print(cfg.dhcp ? "DHCP: waiting..." : "No link");
    }

    oled.setCursor(0, 18);
    if (cfg.protocol == PROTO_FSEQ) {
        oled.print("FSEQ  FPS:");
        oled.print(g_fps);
        oled.setCursor(0, 27);
        if (!g_sdMounted)         oled.print("No SD card");
        else if (g_fseqCount == 0) oled.print("No sequences");
        else {
            oled.print(g_fseqName);
            oled.setCursor(0, 45);
            oled.print(g_fseqFrame);
            oled.print("/");
            oled.print(g_fseqFrames);
        }
    } else {
        oled.print(cfg.protocol == PROTO_DDP ? "DDP" : "E1.31");
        oled.print("  FPS:");
        oled.print(g_fps);

        oled.setCursor(0, 27);
        oled.print("Pkts:");
        oled.print(cfg.protocol == PROTO_DDP ? g_ddpPackets : g_e131Packets);
    }

    oled.setCursor(0, 36);
    char vbuf[22];
    snprintf(vbuf, sizeof(vbuf), "V1:%u.%02uV V2:%u.%02uV",
             g_vin1_mv / 1000, (g_vin1_mv % 1000) / 10,
             g_vin2_mv / 1000, (g_vin2_mv % 1000) / 10);
    oled.print(vbuf);

    if (g_testMode == 5) {
        oled.setCursor(0, 45);
        oled.print("Port ");
        oled.print(g_testPort + 1);
        oled.print(g_testPort % 2 == 0 ? " RED" : " BLUE");
    }

    oled.setCursor(0, 56);
    oled.print("v"); oled.print(FW_VERSION);
    oled.print(" b"); oled.print(FW_BUILD);

    oled.display();
}

void setupOLED() {
    Wire.begin(OLED_SDA, OLED_SCL);
    if (!oled.begin(SSD1306_SWITCHCAPVCC, OLED_ADDR)) {
        Serial.println("OLED not found — display disabled");
        return;
    }
    s_oledFound = true;
    oled.setRotation(2);
    oled.clearDisplay();
    oled.setTextSize(2);
    oled.setTextColor(SSD1306_WHITE);
    oled.setCursor(0, 0);
    oled.println("SBPixel16");
    oled.setTextSize(1);
    oled.setCursor(0, 20);
    oled.print("v"); oled.print(FW_VERSION);
    oled.print(" build "); oled.print(FW_BUILD);
    oled.setCursor(0, 32);
    oled.println("Starting...");
    oled.display();
    Serial.println("OLED: SSD1306 128x64 found");
}

// ── PARLIO LED output ─────────────────────────────────────────────────────────

void setupParlio() {
    g_parlioOk = parlio.begin(cfg);
    if (!g_parlioOk)
        Serial.println("PARLIO init failed!");
}

// ── DMX output ────────────────────────────────────────────────────────────────

void setupDmx() {
    if (!cfg.dmxEnabled) return;
    dmx.begin(DMX_TX_PIN);
}

// ── E1.31 packet parsing ──────────────────────────────────────────────────────

static void parseE131() {
    int pktLen = e131Udp.parsePacket();
    if (pktLen < 638) return;
    e131Udp.read(e131Buf, sizeof(e131Buf));

    if (memcmp(&e131Buf[4], ACN_ID, 12) != 0) return;
    uint32_t rootVec  = ((uint32_t)e131Buf[18] << 24) | ((uint32_t)e131Buf[19] << 16) |
                        ((uint32_t)e131Buf[20] << 8)  |  e131Buf[21];
    uint32_t frameVec = ((uint32_t)e131Buf[40] << 24) | ((uint32_t)e131Buf[41] << 16) |
                        ((uint32_t)e131Buf[42] << 8)  |  e131Buf[43];
    if (rootVec != 0x04 || frameVec != 0x02) return;
    if (e131Buf[117] != 0x02) return;
    if (e131Buf[125] != 0x00) return;

    uint16_t universe  = ((uint16_t)e131Buf[113] << 8) | e131Buf[114];
    const uint8_t *chanData = &e131Buf[126];
    uint16_t chanCount = (uint16_t)(((e131Buf[123] << 8) | e131Buf[124]) - 1);
    if (chanCount > 512) chanCount = 512;

    if (universe < cfg.uniStart) return;

    for (int port = 0; port < NUM_PORTS; port++) {
        uint32_t portAbs0 = cfg.ports[port].startChannel - 1;
        uint32_t portAbs1 = portAbs0 + (uint32_t)cfg.ports[port].pixelCount * 3 - 1;
        uint32_t uniAbs0  = (uint32_t)(universe - cfg.uniStart) * cfg.uniSize;
        uint32_t uniAbs1  = uniAbs0 + chanCount - 1;

        uint32_t ov0 = max(portAbs0, uniAbs0);
        uint32_t ov1 = min(portAbs1, uniAbs1);
        if (ov0 > ov1) continue;

        uint32_t copyLen  = ov1 - ov0 + 1;
        uint32_t uniOff   = ov0 - uniAbs0;
        uint32_t portOff  = ov0 - portAbs0;

        memcpy(rawBuf[port] + portOff, chanData + uniOff, copyLen);
    }

    // DMX output fill
    if (cfg.dmxEnabled) {
        uint32_t dmxAbs0 = cfg.dmxStartCh - 1;
        uint32_t dmxAbs1 = dmxAbs0 + 511;
        uint32_t uniAbs0 = (uint32_t)(universe - cfg.uniStart) * cfg.uniSize;
        uint32_t uniAbs1 = uniAbs0 + chanCount - 1;
        uint32_t ov0 = max(dmxAbs0, uniAbs0);
        uint32_t ov1 = min(dmxAbs1, uniAbs1);
        if (ov0 <= ov1)
            memcpy(dmxBuf + (ov0 - dmxAbs0), chanData + (ov0 - uniAbs0), ov1 - ov0 + 1);
    }

    g_lastPacket = millis();
    g_e131Packets++;
}

// ── DDP packet parsing ────────────────────────────────────────────────────────

static void parseDDP() {
    int pktLen = ddpUdp.parsePacket();
    if (pktLen < 10) return;
    int len = ddpUdp.read(ddpBuf, sizeof(ddpBuf));

    uint8_t  flags  = ddpBuf[0];
    uint8_t  type   = ddpBuf[2];
    uint32_t offset = ((uint32_t)ddpBuf[4] << 24) | ((uint32_t)ddpBuf[5] << 16) |
                      ((uint32_t)ddpBuf[6] << 8)  |  ddpBuf[7];
    uint16_t dlen   = ((uint16_t)ddpBuf[8] << 8)  |  ddpBuf[9];

    if (!(flags & 0x01)) return;
    if (type != 0x01)    return;

    if (10 + dlen > len) dlen = (uint16_t)(len - 10);
    const uint8_t *data = &ddpBuf[10];

    uint32_t pktAbs0 = offset;
    uint32_t pktAbs1 = offset + dlen - 1;

    for (int port = 0; port < NUM_PORTS; port++) {
        uint32_t portAbs0 = cfg.ports[port].startChannel - 1;
        uint32_t portAbs1 = portAbs0 + (uint32_t)cfg.ports[port].pixelCount * 3 - 1;

        uint32_t ov0 = max(portAbs0, pktAbs0);
        uint32_t ov1 = min(portAbs1, pktAbs1);
        if (ov0 > ov1) continue;

        uint32_t copyLen = ov1 - ov0 + 1;
        uint32_t pktOff  = ov0 - pktAbs0;
        uint32_t portOff = ov0 - portAbs0;

        memcpy(rawBuf[port] + portOff, data + pktOff, copyLen);
    }

    // DMX output fill
    if (cfg.dmxEnabled) {
        uint32_t dmxAbs0 = cfg.dmxStartCh - 1;
        uint32_t dmxAbs1 = dmxAbs0 + 511;
        uint32_t ov0 = max(dmxAbs0, pktAbs0);
        uint32_t ov1 = min(dmxAbs1, pktAbs1);
        if (ov0 <= ov1)
            memcpy(dmxBuf + (ov0 - dmxAbs0), data + (ov0 - pktAbs0), ov1 - ov0 + 1);
    }

    g_lastPacket = millis();
    g_ddpPackets++;
}

// ── ADC ───────────────────────────────────────────────────────────────────────

static uint32_t s_adcTimer = 0;

static uint32_t oversample(int pin) {
    uint32_t sum = 0;
    for (int i = 0; i < ADC_SAMPLES; i++) sum += analogReadMilliVolts(pin);
    return sum / ADC_SAMPLES;
}

void readADC() {
    uint32_t now = millis();
    if (now - s_adcTimer < 500) return;
    s_adcTimer = now;
    g_vin1_mv = oversample(VIN1_PIN) * VIN_DIV_NUM / VIN_DIV_DEN;
    g_vin2_mv = oversample(VIN2_PIN) * VIN_DIV_NUM / VIN_DIV_DEN;
}

void setupADC() {
    analogReadResolution(12);
    analogSetAttenuation(ADC_11db);
    g_vin1_mv = oversample(VIN1_PIN) * VIN_DIV_NUM / VIN_DIV_DEN;
    g_vin2_mv = oversample(VIN2_PIN) * VIN_DIV_NUM / VIN_DIV_DEN;
}

// ── Buttons ───────────────────────────────────────────────────────────────────

static bool     s_b1Prev = false;   // pressed = true
static bool     s_b2Prev = false;
static uint32_t s_b1Down = 0;
static uint32_t s_b1Rep  = 0;
static uint32_t s_b2Down = 0;
static bool     s_b2Consumed = false;   // BTN2 long-press-to-enter consumed this hold

static uint8_t  s_portCycle = 0;        // active port in the port-cycle test (mode 5)
static uint32_t s_portCycleTimer = 0;

static const char* testModeName() {
    switch (g_testMode) {
        case 1: return "RED";
        case 2: return "GREEN";
        case 3: return "BLUE";
        case 4: return "RAINBOW";
        case 5: return "PORTS";
        default: return "OFF";
    }
}

void setupButtons() {
    pinMode(BTN1_PIN, INPUT_PULLUP);
    pinMode(BTN2_PIN, INPUT_PULLUP);
}
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
void loop() {
    uint32_t now = millis();

    // While an OTA upload is running, hand the CPU + flash bus to the async
    // web-server task: skip pixel rendering entirely and just yield. Cleared
    // by a timeout if the upload aborts without a final chunk.
    if (g_otaActive) {
        if (now - g_otaLastMs > 5000) g_otaActive = false;
        else { delay(2); return; }
    }

    checkButtons();
    netMenu.tick();
    g_menuActive = netMenu.active();
    readADC();

    if (g_testMode == 0) {
        if (cfg.protocol == PROTO_FSEQ) {
            fseq.begin();      // lazy mount on first FSEQ use (no-op after first)
            fseq.tick(rawBuf, cfg, dmxBuf);
        } else if (s_ethConnected) {
            if (cfg.protocol == PROTO_E131) parseE131();
            else                            parseDDP();
        }
    }

    if (now - s_refreshTimer >= REFRESH) {
        s_refreshTimer = now;

        if (g_testMode > 0) {
            applyTestPattern();
        } else if (g_lastPacket && (now - g_lastPacket) > DATA_TIMEOUT) {
            memset(rawBuf, 0, sizeof(rawBuf));
            g_lastPacket = 0;
        }

        parlio.show(rawBuf, cfg);
        if (cfg.dmxEnabled) dmx.send(dmxBuf, cfg.dmxChannels);
        s_frameCount++;
    }

    if (now - s_fpsTimer >= 1000) {
        g_fps        = s_frameCount;
        s_frameCount = 0;
        s_fpsTimer   = now;
        updateOLED();
    }
}

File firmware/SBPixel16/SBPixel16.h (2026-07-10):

#pragma once

// ── Firmware version ──────────────────────────────────────────────────────────
#define FW_VERSION    "1.0.0"                 // semantic version (bump on release)
#define FW_BUILD      17                      // build number (bump each flashed build)
#define FW_BUILD_DATE (__DATE__ " " __TIME__) // compile timestamp = unique build id

// ── Board / port constants ────────────────────────────────────────────────────

#define NUM_PORTS       16
#define MAX_PIXELS      340     // max pixels per port; increase if needed (affects FPS)
#define DATA_TIMEOUT    1000    // ms before clearing pixels on no data
#define REFRESH         25      // ms between FastLED.show() calls (~40fps target)
#define PORT_CYCLE_MS   2000    // port-cycle test: ms each port stays lit
#define HTTP_PORT       80
#define E131_UDP_PORT   5568
#define DDP_UDP_PORT    4048
#define CONFIG_FILE     "/config.json"

// ── GPIO output pins for the 16 pixel ports ───────────────────────────────────
// Pin assignments taken directly from the board schematic DATA1–DATA16 labels.
// NOTE: DATA14=GPIO24 (USB DM) and DATA16=GPIO25 (USB DP) — using these for
// pixel output disables USB on-the-fly; acceptable since USB is not needed here.
#define PIN_P0   19   // DATA1
#define PIN_P1   18   // DATA2
#define PIN_P2   17   // DATA3
#define PIN_P3   16   // DATA4
#define PIN_P4   15   // DATA5
#define PIN_P5   14   // DATA6
#define PIN_P6    6   // DATA7
#define PIN_P7    5   // DATA8
#define PIN_P8    4   // DATA9
#define PIN_P9    3   // DATA10
#define PIN_P10   2   // DATA11

// ── Board revision: pixel ports 12-16 (PIN_P11..PIN_P15) differ per HW rev ─────
// HW1 = original board.  HW2 = revised board that reroutes ports 12-16 (notably
// 14 & 16 off the USB pins GPIO24/25).  Build HW2 with -DHW_VERSION=2, or change
// the default below.
#ifndef HW_VERSION
#define HW_VERSION  1
#endif

#if HW_VERSION >= 2
  // ---- HW2 (revised board): ports 12-16 remapped off the USB pins ----
  #define PIN_P11  32   // DATA12  (port 12)  was GPIO46
  #define PIN_P12  33   // DATA13  (port 13)  was GPIO47
  #define PIN_P13  46   // DATA14  (port 14)  was GPIO24 (USB DM)
  #define PIN_P14  47   // DATA15  (port 15)  was GPIO48
  #define PIN_P15  48   // DATA16  (port 16)  was GPIO25 (USB DP)
#else
  // ---- HW1 (original board) ----
  #define PIN_P11  46   // DATA12
  #define PIN_P12  47   // DATA13
  #define PIN_P13  24   // DATA14  (USB DM — dead on HW1)
  #define PIN_P14  48   // DATA15
  #define PIN_P15  25   // DATA16  (USB DP — dead on HW1)
#endif

// ── Ethernet PHY (IP101GRI on Waveshare ESP32-P4-ETH) ─────────────────────────
#define ETH_PHY_TYPE    ETH_PHY_IP101
#define ETH_PHY_ADDR    1
#define ETH_PHY_MDC     31
#define ETH_PHY_MDIO    52
#define ETH_PHY_POWER   51      // PHY reset / power-enable
#define ETH_CLK_MODE    EMAC_CLK_EXT_IN  // 50 MHz ext crystal → GPIO50

// ── OLED (SSD1306 128×64, I2C) ───────────────────────────────────────────────
// Uses the Waveshare board's default I2C bus.
#define OLED_SDA    7
#define OLED_SCL    8
#define OLED_ADDR   0x3C
#define OLED_W      128
#define OLED_H      64

// ── microSD (SDIO 4-bit, on the ESP32-P4-ETH module) ──────────────────────────
// Card slot lives on the Waveshare module, not the SBPixel16 PCB. SDMMC signals:
#define SD_CLK_PIN  43
#define SD_CMD_PIN  44
#define SD_D0_PIN   39
#define SD_D1_PIN   40
#define SD_D2_PIN   41
#define SD_D3_PIN   42
#define SD_PWR_PIN  45      // Q1 high-side P-FET: drive LOW to power the card
#define FSEQ_DIR    "/sequences"   // sequences played in a loop from here
#define SD_CONFIG_FILE "/config.json"   // optional config override, SD card root

// ── ADC inputs ────────────────────────────────────────────────────────────────
#define VIN1_PIN    20   // VIN1_ADC
#define VIN2_PIN    21   // VIN2_ADC
#define ADC_SAMPLES  8   // oversampling count for noise reduction
// VIN sense divider (per schematic): VINx --[10k]-- node --[680]-- GND,
// node --[100]-- ADC pin. Actual VIN = pin_mV * (10000+680)/680.
#define VIN_DIV_NUM  10680
#define VIN_DIV_DEN  680

// ── Buttons ───────────────────────────────────────────────────────────────────
#define BTN1_PIN    26   // test-cycle button (active LOW, internal pull-up)
#define BTN2_PIN    27   // test-stop  button (active LOW, internal pull-up)
#define BTN_DEBOUNCE_MS  50
#define LONGPRESS_MS    1500   // hold BTN1 this long to open the OLED network menu
#define REPEAT_DELAY_MS  500   // hold-to-repeat: delay before auto-repeat starts
#define REPEAT_RATE_MS   120   // hold-to-repeat: interval between repeats

// ── Pixel output limits ───────────────────────────────────────────────────────
#define MAX_NULL_PIXELS  50    // max null/sacrificial pixels per port
#define MAX_GROUPING      8    // max physical LEDs per logical channel group

// ── Color order (wire order of the physical LED) ──────────────────────────────
// FastLED NEOPIXEL sends bytes as G,R,B. These constants drive the permutation
// that makes each physical LED type receive the correct byte sequence.
#define CO_GRB  0   // WS2812 / WS2811 default
#define CO_RGB  1
#define CO_BGR  2
#define CO_RBG  3
#define CO_GBR  4
#define CO_BRG  5

// ── Input protocol ────────────────────────────────────────────────────────────
#define PROTO_E131  0
#define PROTO_DDP   1
#define PROTO_FSEQ  2   // play FSEQ files from microSD in an endless loop

// ── Config structs ────────────────────────────────────────────────────────────

typedef struct {
    uint16_t pixelCount;    // logical pixel count (unique channel groups)
    uint32_t startChannel;  // absolute 1-based channel index
    uint8_t  colorOrder;    // CO_GRB … CO_BRG (default CO_GRB = 0)
    uint8_t  nullPixels;    // sacrificial pixels sent before data (0–MAX_NULL_PIXELS)
    uint8_t  grouping;      // physical LEDs per logical pixel (1 = no grouping)
    uint8_t  brightness;    // per-port output brightness, percent (0-100)
} PortConfig;

typedef struct {
    bool     dhcp      = false;
    String   ip        = "192.168.1.200";
    String   subnet    = "255.255.255.0";
    String   gateway   = "192.168.1.1";
    uint8_t  protocol  = PROTO_E131;
    uint16_t uniStart  = 1;
    uint16_t uniSize   = 510;
    PortConfig ports[NUM_PORTS];
    // DMX output
    bool     dmxEnabled  = false;
    uint32_t dmxStartCh  = 1;
    uint16_t dmxChannels = 512;

#define DMX_TX_PIN 54
} AppConfig;

// ── Runtime stats (updated in loop) ──────────────────────────────────────────
extern uint32_t g_e131Packets;
extern uint32_t g_ddpPackets;
extern uint32_t g_fps;
extern uint32_t g_lastPacket;

// ADC readings (millivolts, updated every 500 ms)
extern uint32_t g_vin1_mv;
extern uint32_t g_vin2_mv;

// Test mode: 0=off 1=red 2=green 3=blue 4=rainbow 5=port-cycle
extern uint8_t  g_testMode;
extern uint8_t  g_testPort;   // active port (0-based) in the port-cycle test

// True if the PARLIO WS2812 driver initialized OK (else pixel output is dead).
extern bool g_parlioOk;
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

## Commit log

2026-07-03 Add OLED network editor and microSD FSEQ playback
    Feature 1: two-button OLED network setup (net_menu.h) — long-press BTN1
    to set DHCP / static IP / gateway from the front panel, saves and reboots.
    Feature 2: standalone FSEQ playback from microSD (fseq_player.h) — new
    PROTO_FSEQ mode plays uncompressed FSEQ v2 sequences (full or sparse) from
    /sequences on the module's SDIO card, looping the folder forever. Frames
    scatter into ports via the same absolute-channel model as E1.31/DDP.
    Web UI: FSEQ protocol option on the Network page; dashboard shows SD card
    status and the sequence now playing (new fields in /api/status). Also add
    .gitignore for build output and KiCad backups, and refresh th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
    [SBPixel16.h, SBPixel16.ino, fseq_player.h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]
2026-07-04 Fix dark pixels/menu, correct VIN scaling, add firmware build number
    - Init microSD before PARLIO in setup(): bringing up SDMMC after PARLIO
    stalled its DMA, leaving pixels dark and the loop sluggish (which also
    broke the long-press OLED menu). Ordering SD first fixes both.
    - Scale VIN ADC readings by the board divider (10k/680R, x15.71) so the
    OLED/web report the real input voltage instead of the raw pin voltage.
    - Add firmware version + build number: shown on the OLED (boot splash and
    status footer) and the web dashboard, and exposed via /api/status.
    [SBPixel16.h, SBPixel16.ino]
2026-07-06 Fix dark pixels: don't init microSD in E1.31/DDP mode
    Root cause of all-ports-dark output: SD_MMC.begin() at boot clobbers the
    PARLIO WS2812 driver (shared peripheral/DMA), so parlio.begin() failed and
    show() silently no-op'd while fps still read 40. Only bring up the SD card
    when protocol==FSEQ; E1.31/DDP now leaves PARLIO untouched and pixels work
    (verified on port 1: red/green/blue test cycle + BTN2 stop).
    Also:
    - fseq.begin() is now idempotent (guarded) and lazily mounts on first FSEQ use
    - expose parlioOk / menuActive / b1HeldMs in /api/status for remote diagnosis
    - suspend pixel rendering during OTA and pass image size to Update.begin()
    (OTA drain is flash-erase-bound ~16 KB/s; thro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
    [SBPixel16.h, SBPixel16.ino, fseq_player.h]
2026-07-06 Add CI firmware build; HW1/HW2 pin options; SD/PSRAM/OTA fixes
    CI: .github/workflows/build-firmware.yml builds both HW variants with
    arduino-cli (esp32:esp32:esp32p4:PSRAM=enabled) and uploads the .bin
    artifacts. NOTE: firmware must be built with PSRAM=enabled — the board's
    PSRAM defaults to Disabled, which left getPsramSize()=0.
    Firmware:
    - HW_VERSION build switch: HW1 (default) = original pins; HW2 (-DHW_VERSION=2)
    reroutes pixel ports 12-16 to GPIO32,33,46,47,48 (off the USB pins), per the
    revised schematic.
    - SD: use the esp32p4 variant's auto-config (SLOT-0 IOMUX, LDO ch4, power pin)
    instead of custom setPins/power handling; only mount in FSEQ mode so it can't
    disturb PARLIO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
    [ESP32-P4_16.kicad_pcb, ESP32.kicad_sch]
2026-07-06 Add KiCad CI: ERC/DRC + gerbers, drill, schematic PDF, BOM, pick&place
    Runs kicad-cli in the KiCad 10 container on hardware changes: ERC/DRC
    reports (non-blocking, board is WIP), schematic PDF, BOM, and a zipped
    gerber+drill fabrication package uploaded as an artifact.
2026-07-06 Fix KiCad CI: drop zip step (not in container), make ERC/DRC report-only
2026-07-06 v2 fix
    [ESP32-P4_16.kicad_pcb, ESP32-P4_16.kicad_sch, ESP32.kicad_sch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]
2026-07-06 Mount microSD at boot — fixes SD detection
    The card mounts fine (16 GB, 4-bit) with the esp32p4 variant auto-config
    (SLOT-0 IOMUX, on-chip LDO ch4, power pin 45). It only ever "failed" because
    (1) the board's otadata pointed at a stale OTA app partition so serial flashes
    to app0 were ignored, and (2) mounting lazily in loop() after Ethernet was up
    didn't work. Mounting at boot right after setupParlio() works and coexists with
    PARLIO (needs on-LED confirmation, but boots clean). SD now mounts in all modes,
    so the web UI shows the card. FSEQ still needs .fseq files in /sequences.
    [SBPixel16.h, SBPixel16.ino, fseq_player.h]
2026-07-06 Add SD-card icon to OLED header when a card is mounted
    Small 8x11 glyph in the top-right of the status screen, shown in all modes
    whenever g_sdMounted is true.
2026-07-06 Shorten OLED test-mode label so RAINBOW doesn't overflow the line
    "[TEST:RAINBOW]" (~84px) ran off the 128px screen and into the SD icon;
    use compact "T:<name>" which fits before the icon.
    [SBPixel16.h, SBPixel16.ino]
2026-07-06 Rework buttons: BTN1 cycles test modes, long-press BTN2 opens the menu
    - BTN1 tap: cycle Off->Red->Green->Blue->Rainbow->Off
    - BTN2 long-press: enter the OLED network menu (was BTN1)
    - BTN2 tap: stop test pattern
    - In menu: BTN1 changes value (hold to repeat), BTN2 advances/commits
    [SBPixel16.h, SBPixel16.ino]
2026-07-06 Update README: new button scheme, PSRAM build flag, HW1/HW2, SD status
2026-07-06 Update PCB layout
    [ESP32-P4_16.kicad_pcb]
2026-07-07 update to new connectors
    [ESP32-P4_16.kicad_pcb, ESP32-P4_16.kicad_sch, Output1_8.kicad_sch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]
2026-07-10 Load /config.json from the SD card on boot if present
    After the SD card mounts, check for /config.json at its root and merge it
    over the current config (jsonToConfig only changes fields present in the
    file), then mirror the result to LittleFS so it persists. Lets a card be
    used to provision or carry a controller's config between units.
    pixelCount/nullPixels/grouping determine PARLIO's DMA buffer size, which is
    fixed at parlio.begin() (already run by this point) and can't be resized
    live — if the SD config changes any of those, reboot so the next boot sizes
    PARLIO correctly. Other fields (network, protocol, brightness, colorOrder,
    startChannel, DMX) apply immediately without a reboot.
    Co-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
    [SBPixel16.h, SBPixel16.ino]
2026-07-10 Add config export/import to the web UI
    Network page gets a Backup/Restore Config panel: Export downloads the
    current /api/config as a timestamped JSON file; Import reads a chosen
    file, validates it's JSON, and POSTs it to /api/config. No backend changes
    needed — /api/config already returns/accepts the full config (network,
    protocol, all 16 ports, DMX). Import note calls out that pixel/null/
    grouping changes need a reboot to take effect, matching the ports page.
